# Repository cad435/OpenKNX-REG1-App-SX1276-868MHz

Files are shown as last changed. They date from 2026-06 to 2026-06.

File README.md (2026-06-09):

# REG1-RP2040-SX1276-868MHz

LoRa-Funkerweiterung (Semtech **SX1276**) für den **OpenKNX RP2040 REG1**-Controller.



Das Add-on bindet ein **SX1276-Funkmodul** per **SPI** an den RP2040 an und führt die
Antenne auf eine **SMA-Buchse**. Damit lässt sich ein REG1-Gerät um LoRa-Funk
(z. B. 433 / 868 / 915 MHz) erweitern.

---

## Funktion

Der SX1276 wird vollständig über **SPI + drei Steuerleitungen** angesprochen:

- **SPI:** SCK, MOSI, MISO, NSS — gemappt auf die **Hardware-SPI1** des RP2040 (GPIO26–29)
- **RESET** (active low)
- **DIO0** — Interrupt (TxDone / RxDone), für den Betrieb zwingend
- **DIO1** — optionaler Interrupt (RxTimeout, LoRaWAN, RadioLib)

Versorgung **3,3 V** (SX1276 ist 3,3-V-only; RP2040 ebenfalls → keine Pegelwandler nötig).
Die Antenne läuft über eine **50-Ω-Leitung** zur SMA-Buchse.

---

## Anschluss J1 (1×10 Stiftleiste zum REG1-Controller / J107)

| Pin | Netz (Add-on) | RP2040 GPIO | SX1276 | Funktion |
|----:|---|---|---|---|
| 1 | VCC2 | – (Vcc2) | – | nicht genutzt |
| 2 | 3V3 | 3V3 | VCC | 3,3 V Versorgung |
| 3 | GND_KNX | GND | GND | Masse |
| 4 | SPI_CSN | GPIO29 | NSS | SPI1 Chip-Select |
| 5 | SPI_MISO | GPIO28 | MISO | SPI1 RX |
| 6 | SPI_MOSI | GPIO27 | MOSI | SPI1 TX |
| 7 | SPI_SCK | GPIO26 | SCK | SPI1 SCK |
| 8 | SX_DIO1 | GPIO18 | DIO1 | IRQ (optional) |
| 9 | SX_RST | GPIO17 | RESET  | Reset (active low) |
| 10  | SX_DIO0 | GPIO16 | DIO0 | IRQ (TxDone/RxDone) |

Genutzt werden **3V3, GND, GPIO16/17/18 und GPIO26–29**; Pin 1 (Vcc2) bleibt unbelegt.

---

## Stromversorgung & TX-Hinweise

Der Funk wird aus der **3,3-V-Schiene der NanoBCU** versorgt. Beim Senden zieht der
SX1276 **bis ~120 mA für die gesamte Sendedauer** (LoRa „Time on Air": ~40 ms bei SF7
bis ~1,15 s bei SF12) — kein kurzer Spike, sondern Dauerstrom.

Empfehlungen für sicheren Betrieb:

- An der NanoBCU (NCN5130) den **2. DC-DC (DC2) auf 3,3 V** für den Funk nutzen und den
  **Bus-Strom hoch einstellen** (FANIN/R6 → 40 mA Buslast; in ETS entsprechend anmelden).
- **TX-Leistung ≤ +17 dBm (~90 mA)** wählen — bleibt unter der DC2-Überstromschwelle (~100 mA).
- Lokal am Modul **100 nF + 10–47 µF** Entkopplung; der eigentliche Burst-Puffer ist der
  VFILT-Stützkondensator der NanoBCU.

---

## Antennen-Routing

- **SMA-Buchse**, Antennenleitung als **50-Ω Grounded Coplanar Waveguide (CBCPW)**.
- 2-Lagen-FR4 (Dk ≈ 4,4 @ 1 GHz), durchgehende GND-Fläche auf Bottom.
- Trace **1,5 mm**, Gap zur Coplanar-GND **0,45 mm**, beidseitiges **Via-Stitching** zur
  Bottom-GND. Leitung kurz und gerade zum SMA-Innenleiter.

---

## Inhalt des Repositories

| Datei | Beschreibung |
|---|---|
| `REG1-RP2040-SX1276-1x_V0.1-Schematic.PDF` | Schaltplan |
| `REG1-RP2040-SX1276-1x_V0.1_Assembly.PDF`  | Bestückungsplan (Top/Bottom, realistische Ansicht) |
| `BOM-REG1-RP2040-SX1276-1x(V0.1).pdf` | Stückliste |
| `JLC_PCBA_BOM-REG1-RP2040-SX1276-1x(V0.1).xlsx` | BOM für JLCPCB-Bestückung |
| `JLC_PCBA_CPL-REG1-RP2040-SX1276-1x(V0.1).xlsx` | Pick-&-Place / CPL für JLCPCB |
| `REG1-RP2040-SX1276-1x_Gerber.zip` | Gerber-Daten zur Fertigung |
| `REG1-RP2040-SX1276-1x(V0.1).step` | 3D-Modell (STEP) |

---

## Fertigung

Vorbereitet für **JLCPCB** (2-Lagen-FR4, 1,6 mm): Gerber-ZIP für die Leiterplatte,
dazu `JLC_PCBA_BOM…` und `JLC_PCBA_CPL…` für die SMD-Bestückung. Die
Antennenleitung ist als 50-Ω-CBCPW ausgelegt (siehe „Antennen-Routing").

---

## Status

Version **V0.1** – in Entwicklung.

## Autor / Lizenz

Hardware-Design © **4R3Ngineering**.
Veröffentlicht als Open-Source-Hardware-Add-on für das [OpenKNX](https://github.com/OpenKNX)-Ökosystem.

Lizenziert unter der **CERN-OHL-S v2** (CERN Open Hardware Licence Version 2 – Strongly Reciprocal) – siehe [`LICENSE`](LICENSE).

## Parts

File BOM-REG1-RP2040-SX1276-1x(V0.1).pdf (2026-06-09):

Comment | Description | Designator | Footprint | Quantity
100uF/6.3V | Capacitor | C1, C2 | C1206 | 2
470uF | Polarized Capacitor (Axial) | C3 | CAPR-5mm | 1
100nF | Capacitor | C4 | C0603 | 1
Header 1x10 | Header 1x10 | J1 | Header 1x10 | 1
SMA (C411575) | | J2 | ANT-TH_KH-SMA-K513- G | 1
0 | Resistor | R2 | R1206 | 1
SX1276S8S+T-X1 | SX1276S8S+T-X1 | U1 | WIRELM-SMD_SX1278S165SY-T-X1 | 1

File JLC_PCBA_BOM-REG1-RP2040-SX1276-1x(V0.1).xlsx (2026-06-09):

Comment | Description | Designator | Footprint | Quantity | JLCPCB Part #
100uF/6.3V | Capacitor | C1, C2 | C1206 | 2 | C15008
470uF | Polarized Capacitor (Axial) | C3 | CAPR-5mm | 1
100nF | Capacitor | C4 | C0603 | 1 | C14663
Header 1x10 | Header 1x10 | J1 | Header 1x10 | 1
SMA (C411575) |  | J2 | ANT-TH_KH-SMA-K513-G | 1 | C411575
0 | Resistor | R2 | R1206 | 1 | C17888
SX1276S8S+T-X1 | SX1276S8S+T-X1 | U1 | WIRELM-SMD_SX1278S165SY-T-X1 | 1 | C718834

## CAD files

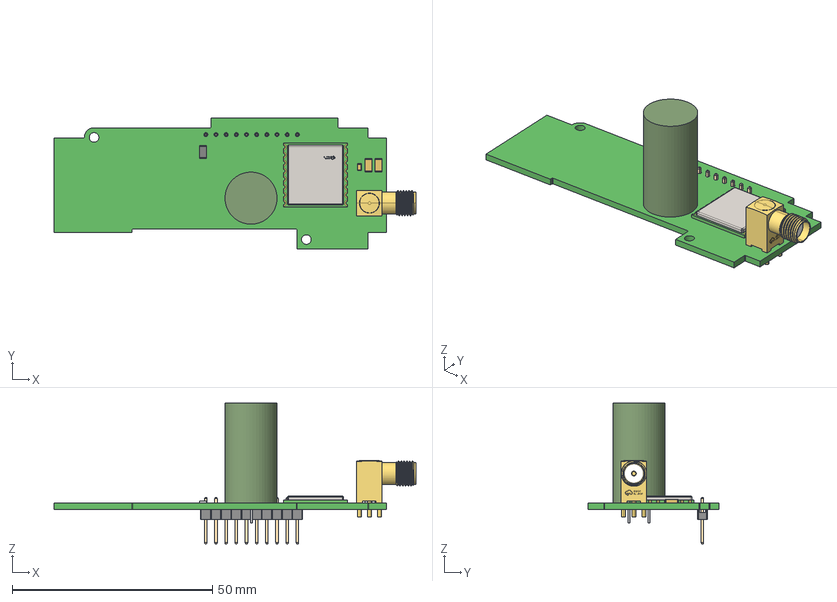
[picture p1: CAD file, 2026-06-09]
REG1-RP2040-SX1276-1x(V0.1).step
90.4 x 32.8 x 35.2 mm

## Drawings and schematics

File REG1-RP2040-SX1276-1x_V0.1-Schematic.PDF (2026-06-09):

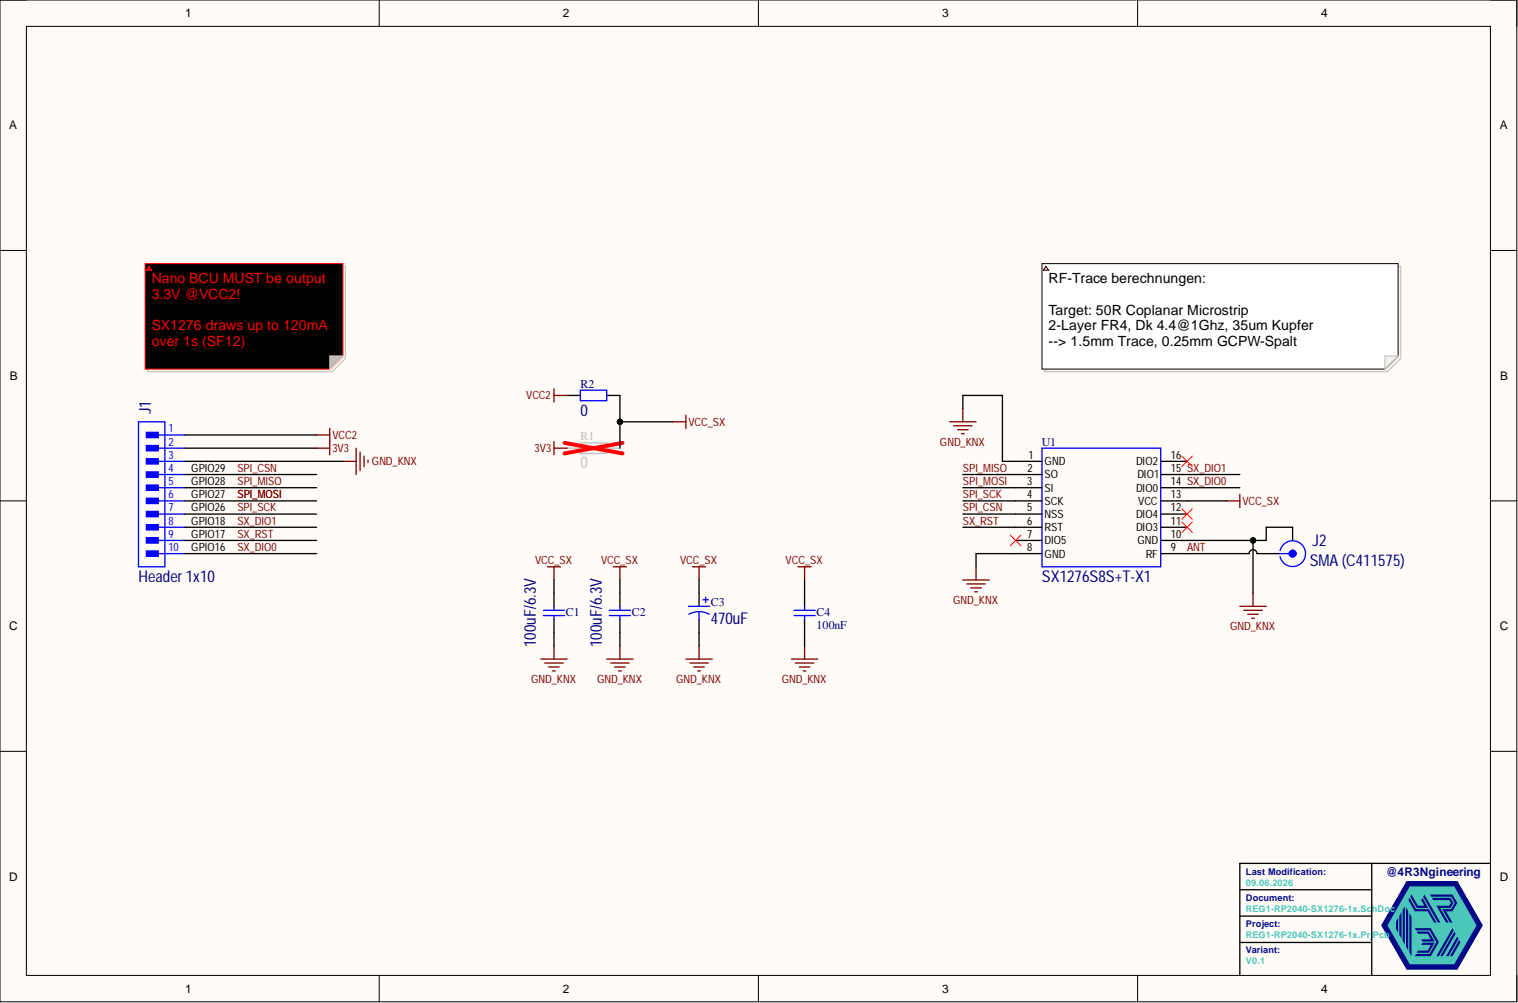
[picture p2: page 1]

Target: 50R Coplanar Microstrip
2-Layer FR4, Dk 4.4@1Ghz, 35um Kupfer --> 1.5mm Trace, 0.25mm GCPW-Spalt

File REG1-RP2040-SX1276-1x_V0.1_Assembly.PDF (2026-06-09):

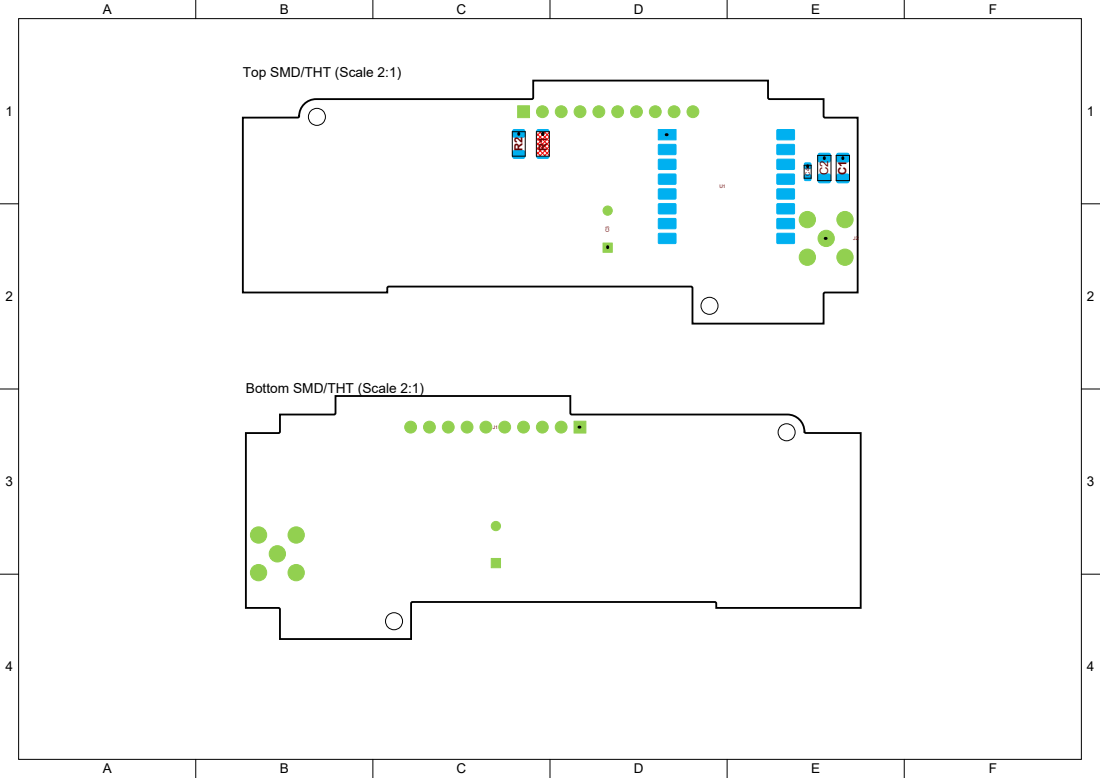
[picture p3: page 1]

Top SMD/THT (Scale 2:1)

Bottom SMD/THT (Scale 2:1)

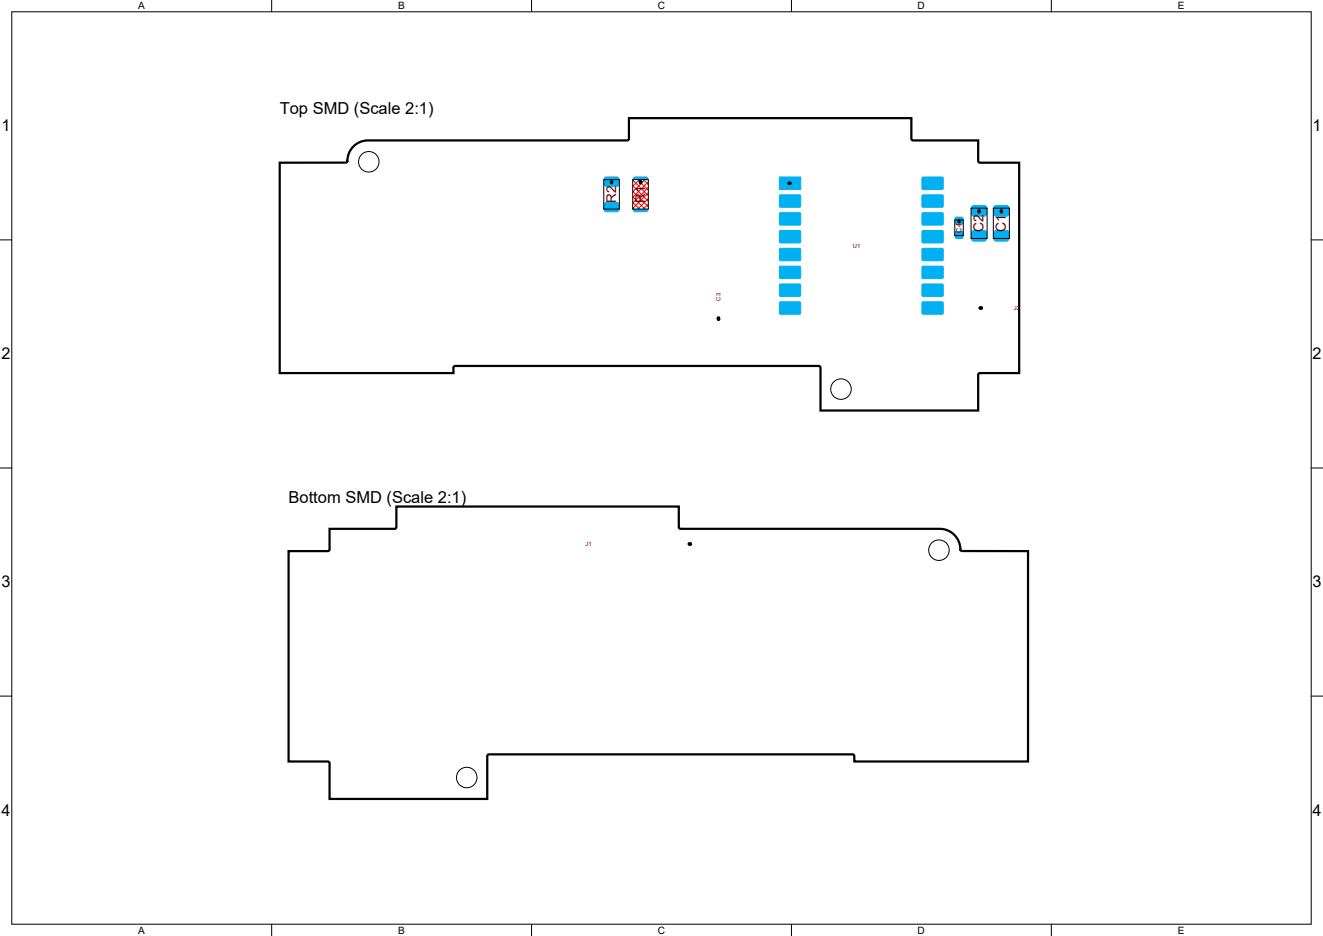
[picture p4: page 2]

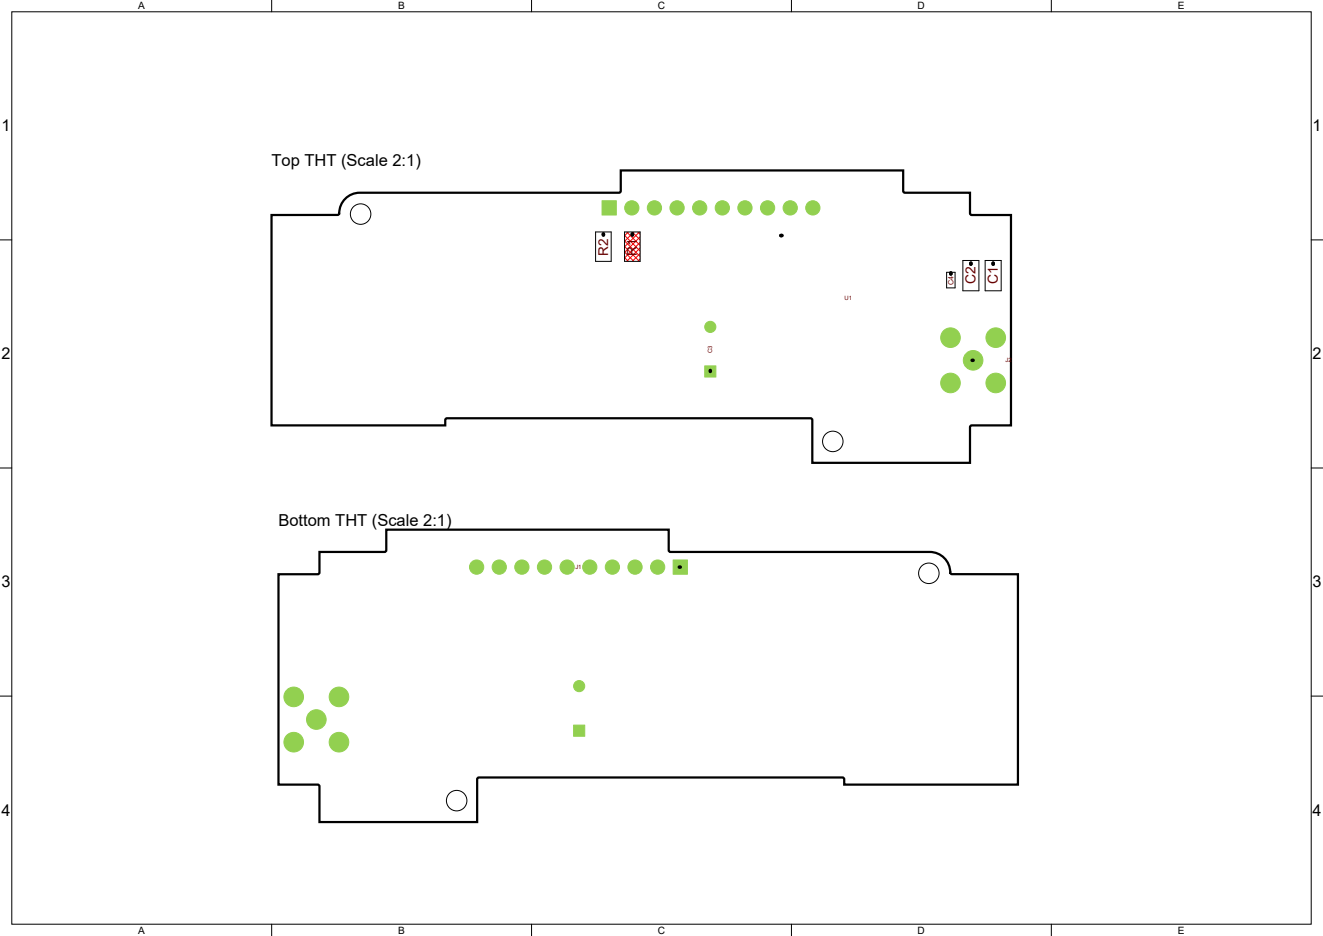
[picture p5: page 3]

1 | 1
2 | 2

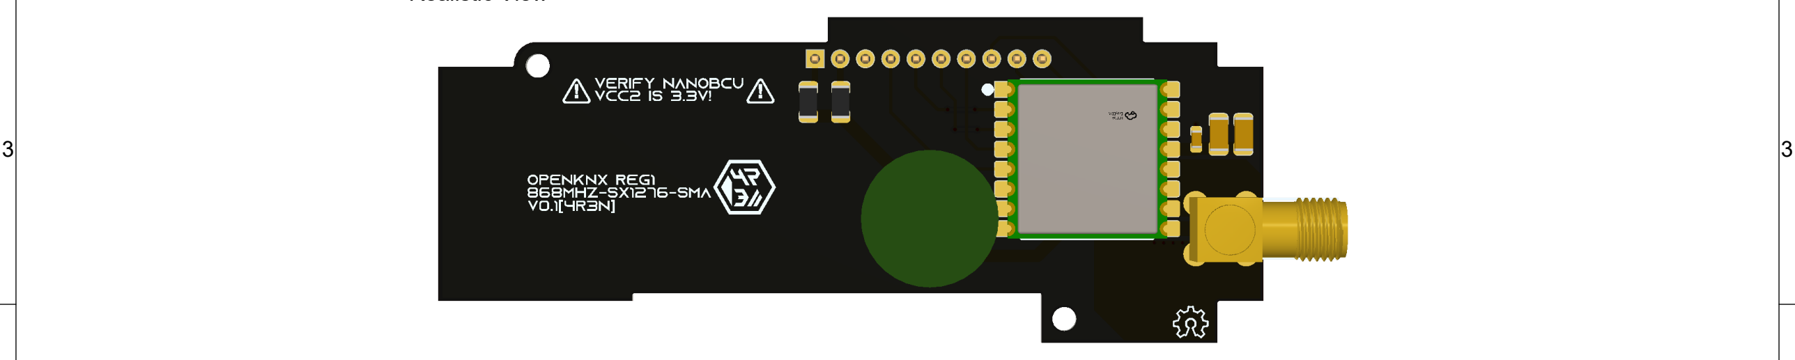
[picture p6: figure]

4 | 4

Realistic View

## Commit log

2026-06-09 Initial commit: REG1-RP2040-SX1276-1x V0.1 hardware release
    SX1276 LoRa add-on for the OpenKNX RP2040 REG1 controller (SPI on HW-SPI1,
    SMA antenna via 50R CBCPW). Includes README, MIT license, schematic,
    assembly drawing, BOM, JLCPCB BOM/CPL, Gerber data and STEP model.
    [JLC_PCBA_BOM-REG1-RP2040-SX1276-1x(V0.1).xlsx, REG1-RP2040-SX1276-1x(V0.1).step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]
2026-06-09 License: switch from MIT to CERN-OHL-S v2; drop RP2040-only note
